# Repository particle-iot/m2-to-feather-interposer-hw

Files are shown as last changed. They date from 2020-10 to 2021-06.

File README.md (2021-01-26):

## M.2 to Feather socket Interposer adapter

### Summary:
Many of our customers have scaled on particle using the feather form factor in order to swap out between Cellular and WiFi products. Unfortunately we are seeing challenges with Cat M1 and the modem sizes that we can offer in the feather form factor. The SA team would like to propose an interposer board between a Particle M.2 Som to an interposer board that can be inserted into a feather socket on a customers PCB.

We recognize our customers may not be able to take advantage of the interposer board if their mechanical assembly does not accommodate the addition Z height and Width required by the addition of an interposer board and an M.2 Som

The interposer board will need to replicate some of the features not found on the M.2 Soms

#### Features:
* Nano SIM Tray
* PMIC, Same PMIC on Boron
* 3.3V@1A Buck regulator like Boron
* Top or Side pressed MODE and RESET buttons
* Enable pin support
* MCO/Board outline is slightly larger than a feather board due to SMT header.

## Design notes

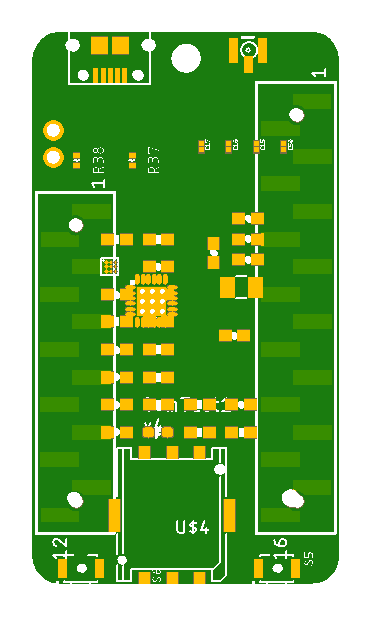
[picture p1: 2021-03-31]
m2_feather_interposer/m2_feather_interposer bottom side.png

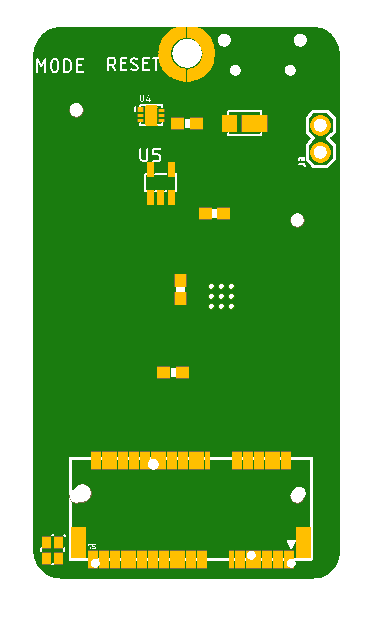
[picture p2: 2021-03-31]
m2_feather_interposer/m2_feather_interposer top side.png

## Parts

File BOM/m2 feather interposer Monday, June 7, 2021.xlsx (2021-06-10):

Done | DK PN | Qty | Value | Device | Package | Parts | Description | AVAILABILITY | DESCRIPTION | MF | MP | PACKAGE | POPULARITY | PRICE | PROD-ID | PROD_ID | PURCHASE-URL | SPICEPREFIX | VALUE
X |  | 1 |  | CONN_02 | 1X02 | J3 | Multi connection point. Often used as Generic Header-pin footprint for 0.1 inch spaced/style header connections
X | 311-0.0JRCT-ND | 2 | 0 | R-US_R0402 | R0402 | R11, R13 | RESISTOR, American symbol
X | 587-1220-1-ND | 1 | 0.001uF | C-USC0402 | C0402 | C11 | CAPACITOR, American symbol
X | 399-7760-1-ND | 1 | 0.01uF | C-USC0402 | C0402 | C1 | CAPACITOR, American symbol
X | 490-6042-1-ND | 1 | 0.047uF | C-USC0402 | C0402 | C12 | CAPACITOR, American symbol
X | 311-100KLRCT-ND | 1 | 100k | R-US_R0402 | R0402 | R17 | RESISTOR, American symbol
X | 490-14571-1-ND | 1 | 100nF | C-USC0201_B | C0201_B | C21 | Capacitor
x | 1276-6854-1-ND | 1 | 100nF | C-USC0603K | C0603K | C20 | CAPACITOR, American symbol |  |  |  |  |  | 5 |  |  |  |  | C
x | 490-14571-1-ND | 1 | 100nF | PARTICLE_C-USC0201_B | PARTICLE_C0201_B | C50 | Capacitor
x | 1276-3431-1-ND | 6 | 10K | R-US_R0402 | R0402 | R1, R9, R10, R11_, R15, R16 | RESISTOR, American symbol
X | 490-18214-1-ND | 6 | 10uF | RICKK2_CAP-10UF-0603 | RICKK2_0603-CAP | C4, C5, C6, C7, C9, C10 | CAP CER 10UF 16V X5R 0805 $ 0.21 |  |  |  |  |  |  |  |  |  |  |  | 10uF
X | 490-18214-1-ND | 2 | 10uF/10V | C-USC0603K | C0603K | C18, C19 | CAPACITOR, American symbol |  |  |  |  |  | 5 |  |  |  |  | C
X | P150LCT-ND | 1 | 150 | R-US_R0402 | R0402 | R5 | RESISTOR, American symbol
x | P20283CT-ND | 1 | 1K | R-US_R0402 | R-US_R0402 | R19 | 0402 Resistor
x | P20283CT-ND | 1 | 1K | R-US_R0402 | R0402 | R12 | RESISTOR, American symbol
x | P20283CT-ND | 3 | 1k | R-US_R0402 | R0402 | R2, R3, R4 | RESISTOR, American symbol
X | 490-10019-1-ND | 1 | 1uF | C-USC0402 | C0402 | C3 | CAPACITOR, American symbol
X | 587-2400-1-ND | 1 | 1uF | CAP-1UF-0603.DEV | 0603-CAP | C2 | CAP CER 1UF 25V X7R 0603 $ 0.10 |  |  |  |  |  |  |  |  |  |  |  | 1uF
X | SRP2512-2R2MCT-ND | 1 | 2.2uH | RICKK2_INDUCTOR-2.2UH | RICKK2_1008-BOURNS | L1 | 2.2uH inductor $0.31 **not ordered yet** |  |  |  |  |  |  |  |  |  |  |  | 2.2uH
X | 311-332LRCT-ND | 1 | 332 | R-US_R0402 | R0402 | R131 | RESISTOR, American symbol
X | 311-4.7KJRCT-ND | 3 | 4.7K | R-US_R0402 | R0402 | R6, R7, R8 | RESISTOR, American symbol
X | 1276-1903-1-ND | 1 | 4.7uF | RICKK2_CAP-4.7UF-0603 | RICKK2_0603-CAP | C8 | Murata X5R series |  |  |  |  |  |  |  |  |  |  |  | 4.7uF
X | 445-6668-1-ND | 1 | 4.7uH | INDUCTOR-SPARKFUNVLS3012ET-4R7M | INDUCTOR-VLS-E | L2 | Inductors
X | 490-14562-1-ND | 3 | 47pF | PARTICLE_C-USC0201_B | PARTICLE_C0201_B | C15, C16, C17 | Capacitor
X | P5.60KLCT-ND | 1 | 5.6K | R-US_R0402 | R0402 | R14 | RESISTOR, American symbol
X | SW1022CT-ND | 2 | B3U-3000P | B3U-3000P | SW_B3U-3000P | S1, S2 | Ultra-small Surface-mounting Tactile Switches with High Contact Reliability Check prices | Warning | Tactile Switch SPST-NO Side Actuated Surface Mount, Right Angle | Omron | B3U-3100P-B | Custom Package Omron |  | None |  |  | https://pricing.snapeda.com/search/part/B3U-3100P-B/?ref=eda
X | 296-49149-1-ND | 1 | BQ24195 | RICKK2_BQ24195 | RICKK2_24VFQN-TI | U2 | Texas Instruments BQ24195LRGER $2.93 |  |  |  |  |  |  |  |  |  |  |  | BQ24195
X | N/A | 2 | ESD NC | REDBEAR_RES0402S | REDBEAR_R-0402S | R37, R38 | RES
X | 2073-SIM8051-6-0-14-01-ACT-ND | 1 | M2_FEATHER_INTERPOSER_PARTICLE_SIM-NANO-4FF | M2_FEATHER_INTERPOSER_PARTICLE_SIM-NANO-4FF | M2_FEATHER_INTERPOSER_PARTICLE_GCT-SIM8100 | U$4 | SIM NANO 4FF
X | MAX17043G+U-ND | 1 | MAX1704X | MAX1704X | TDFN-8 | U3 | MAX17043/MAX17044: Battery Fuel Guage (43 is 1cell, 44 is 2cell) |  |  |  |  |  |  |  | IC-10399
X | TSM-112-01-T-SV-LC-ND |  | SAMTECH 12pin 2.54mm SMT
X | TSM-116-01-T-SV-LC-016-ND |  | SAMTECH 16pin 2.54mm SMT
 | PN in row 32/33 | 1 | MICROBUILDER_FEATHERWINGSMT_BTM_FEATHER | MICROBUILDER_FEATHERWINGSMT_BTM_FEATHER | SMT_BTM_FEATHERWING | MS1
X | 160-1447-1-ND | 1 | RED | LED-RED0603 | LED-0603 | D3 | Red SMD LED |  |  |  |  |  |  |  |  | DIO-00819 |  |  | RED
X | 160-1830-1-ND | 1 | RED | RICKK2_LED-RED | RICKK2_LED-0603 | D1 | LED RED CLEAR 0603 SMD $0.41 |  |  |  |  |  |  |  |  |  |  |  | RED
X | CLMVC-FKA-CL1D1L71BB7C3C3CT-ND | 1 | RICKK2_LED-RGB-CREE-SMD | RICKK2_LED-RGB-CREE-SMD | RICKK2_LED-RGB-CREE-SMD | LED1 | LED RGB DIFFUSED 4SMD $ 0.35
X | 732-7078-1-ND | 1 | RICKK2_M2-STANDOFF | RICKK2_M2-STANDOFF | RICKK2_M2-STANDOFF | U$1 | https://www.digikey.com/product-detail/en/jae-electronics/SM3ZS067U310-NUT1-R1800/670-2864-1-ND/5955848
X | A115904CT-ND | 1 | RICKK2_SPARK_M.2EKEY | RICKK2_SPARK_M.2EKEY | RICKK2_SPARK_M.2EKEY-LESS-CREAM | J1 | $1.42
X | 67T2260 | 1 | RICKK2_USB-MICRO-B-SOCKET-AMPHENOL | RICKK2_USB-MICRO-B-SOCKET-AMPHENOL | RICKK2_USB-B-SMT-AMPHENOL | U$3 | CONN USB MICRO B RECPT SMT R/A $0.42
X | RS1JFPCT-ND | 1 | RS1JFP | RICKK2_DIODE-RS1JFP | RICKK2_SOD-123HE-ON | D2 | Reverse voltage protection diode - not ordered yet! |  |  |  |  |  |  |  |  |  |  |  | RS1JFP
X | 931-1107-1-ND | 1 | UFL | PARTICLE_IPEX-20279-001E | PARTICLE_IPEX-20279-001E | NFC | Ultra Miniature Coaxial SMT RF Receptacle
X | 865-XC8107BC20MR-G | 1 | XC8107SOT25 | XC8107SOT25 | SOT25 | U7
X | 865-XC9258A33EER-G | 1 | XC9258A33EER-G | XC9258A33EER-G | USP-6C | U6 | 1.0A Synchronous Step-Down DC/DC Converters

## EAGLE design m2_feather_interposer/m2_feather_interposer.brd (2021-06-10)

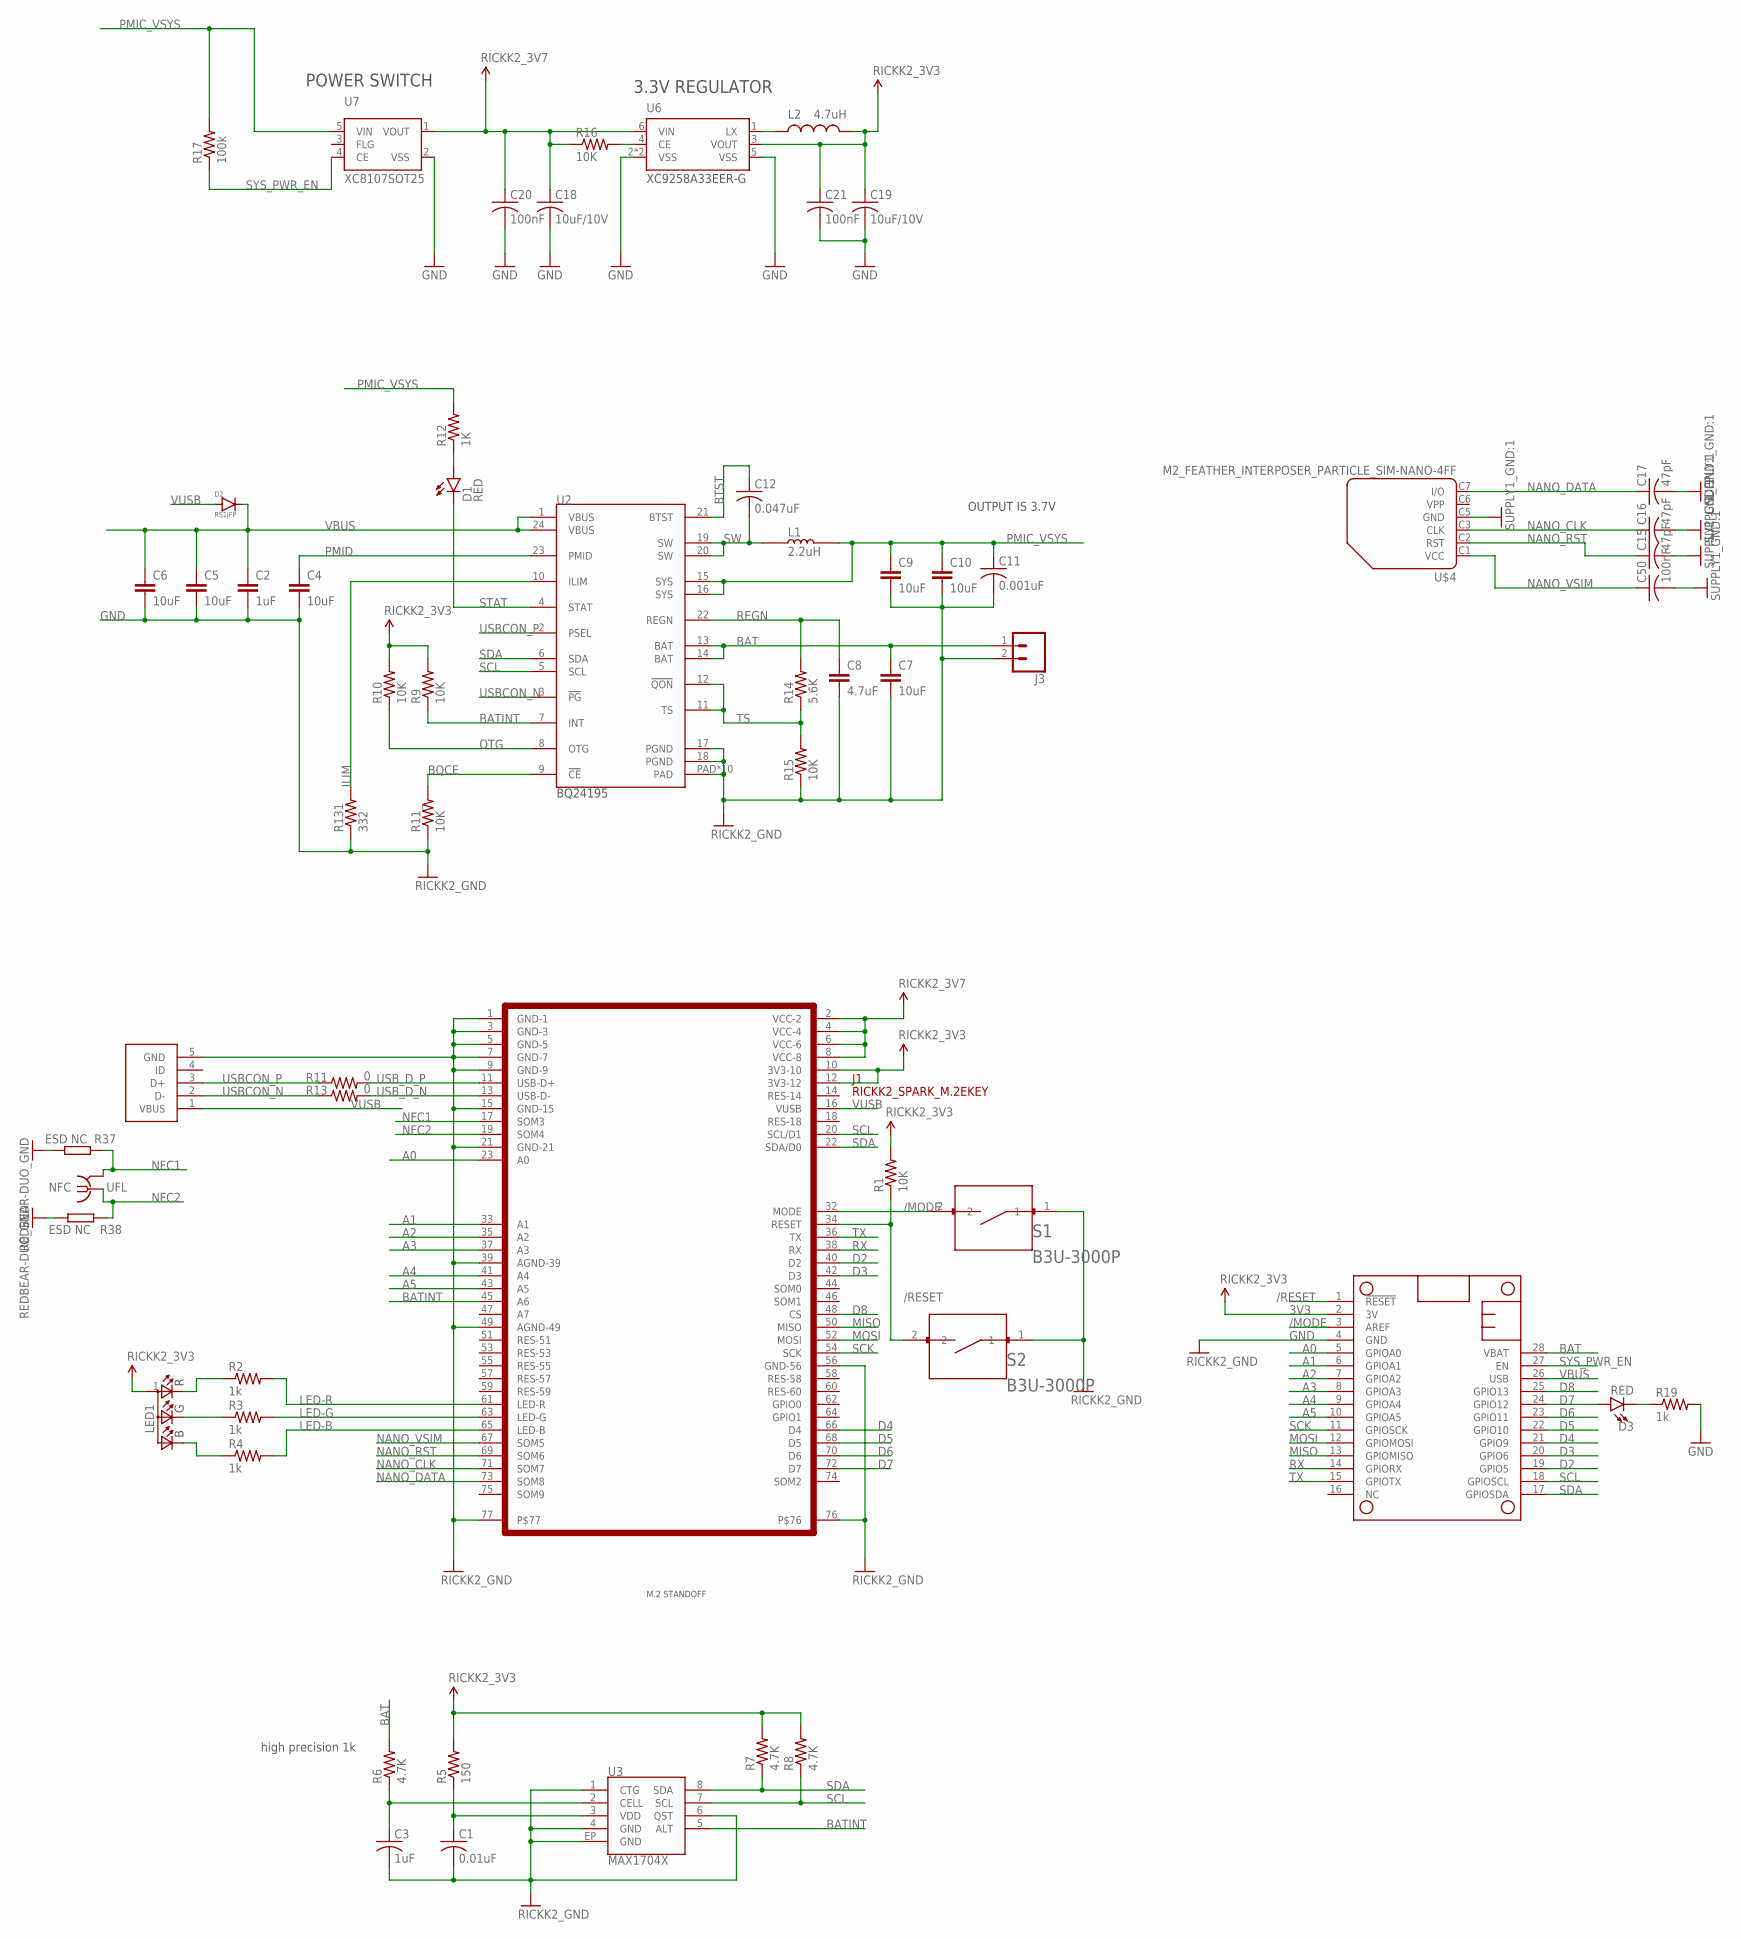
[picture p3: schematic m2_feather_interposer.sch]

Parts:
C1: 0.01uF; C0402
C2: 1uF; 0603-CAP
C3: 1uF; C0402
C4, C5, C6, C7, C9, C10: 10uF; RICKK2_0603-CAP
C8: 4.7uF; RICKK2_0603-CAP
C11: 0.001uF; C0402
C12: 0.047uF; C0402
C15, C16, C17: 47pF; PARTICLE_C0201_B
C18, C19: 10uF/10V; C0603K
C20: 100nF; C0603K
C21: 100nF; C0201_B
C50: 100nF; PARTICLE_C0201_B
D1: RED; RICKK2_LED-0603
D2: RS1JFP; RICKK2_SOD-123HE-ON
D3: RED; LED-0603
J1: RICKK2_SPARK_M.2EKEY; RICKK2_SPARK_M.2EKEY-LESS-CREAM
J3: CONN_02; 1X02
L1: 2.2uH; RICKK2_1008-BOURNS
L2: 4.7uH; INDUCTOR-VLS-E
LED1: RICKK2_LED-RGB-CREE-SMD
MS1: MICROBUILDER_FEATHERWINGSMT_BTM_FEATHER; SMT_BTM_FEATHERWING
NFC: UFL; PARTICLE_IPEX-20279-001E
R1, R9, R10, R11_, R15, R16: 10K; R0402
R2, R3, R4, R19: 1k; R0402
R5: 150; R0402
R6, R7, R8: 4.7K; R0402
R11, R13: 0; R0402
R12: 1K; R0402
R14: 5.6K; R0402
R17: 100k; R0402
R37, R38: ESD NC; REDBEAR_R-0402S
R131: 332; R0402
S1, S2: B3U-3000P; SW_B3U-3000P
U2: BQ24195; RICKK2_24VFQN-TI
U3: MAX1704X; TDFN-8
U6: XC9258A33EER-G; USP-6C
U7: XC8107SOT25; SOT25
U$1: RICKK2_M2-STANDOFF
U$3: RICKK2_USB-MICRO-B-SOCKET-AMPHENOL; RICKK2_USB-B-SMT-AMPHENOL
U$4: M2_FEATHER_INTERPOSER_PARTICLE_SIM-NANO-4FF; M2_FEATHER_INTERPOSER_PARTICLE_GCT-SIM8100

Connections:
3V3: C19.1, C21.1, J1.10 (3V3-10), J1.12 (3V3-12), L2.P$2 (2), LED1.1 (A), MS1.2 (3V), R1.2, R5.2, R7.2, R8.2, R9.2, R10.2, U6.3 (VOUT)
3V7: C18.1, C20.1, J1.2 (VCC-2), J1.4 (VCC-4), J1.6 (VCC-6), J1.8 (VCC-8), R16.1, U6.6 (VIN), U7.1 (VOUT)
/MODE: J1.32 (MODE), MS1.3 (AREF), S1.2
/RESET: J1.34 (RESET), MS1.1 (!RESET), R1.1, S2.2
A0: J1.23 (A0), MS1.5 (GPIOA0)
A1: J1.33 (A1), MS1.6 (GPIOA1)
A2: J1.35 (A2), MS1.7 (GPIOA2)
A3: J1.37 (A3), MS1.8 (GPIOA3)
A4: J1.41 (A4), MS1.9 (GPIOA4)
A5: J1.43 (A5), MS1.10 (GPIOA5)
BAT: C7.1, J3.1, MS1.28 (VBAT), R6.2, U2.13 (BAT), U2.14 (BAT)
BATINT: J1.45 (A6), R9.1, U2.7 (INT), U3.5 (ALT)
BQCE: R11_.2, U2.9 (!CE)
BTST: C12.1, U2.21 (BTST)
D2: J1.40 (D2), MS1.19 (GPIO5)
D3: J1.42 (D3), MS1.20 (GPIO6)
D4: J1.66 (D4), MS1.21 (GPIO9)
D5: J1.68 (D5), MS1.22 (GPIO10)
D6: J1.70 (D6), MS1.23 (GPIO11)
D7: D3.A, J1.72 (D7), MS1.24 (GPIO12)
D8: J1.48 (CS), MS1.25 (GPIO13)
GND: C1.2, C2.2, C3.2, C4.2, C5.2, C6.2, C7.2, C8.2, C9.2, C10.2, C11.2, C15.2, C16.2, C17.2, C18.2, C19.2, C20.2, C21.2, C50.2, J1.1 (GND-1), J1.3 (GND-3), J1.5 (GND-5), J1.7 (GND-7), J1.9 (GND-9), J1.15 (GND-15), J1.21 (GND-21), J1.39 (AGND-39), J1.49 (AGND-49), J1.56 (GND-56), J1.76, J1.77, J3.2, MS1.4 (GND), R11_.1, R15.1, R19.2, R37.2, R38.1, R131.1, S1.1, S2.1, U2.17 (PGND), U2.18 (PGND), U2.PAD, U2.PAD@1 (PAD), U2.PAD@2 (PAD), U2.PAD@3 (PAD), U2.PAD@4 (PAD), U2.PAD@5 (PAD), U2.PAD@6 (PAD), U2.PAD@7 (PAD), U2.PAD@8 (PAD), U2.PAD@9 (PAD), U3.1 (CTG), U3.4 (GND), U3.6 (QST), U3.EP (GND), U6.2 (VSS), U6.5 (VSS), U6.P$1 (VSS), U7.2 (VSS), U$3.5 (GND), U$4.C5 (GND)
ILIM: R131.2, U2.10 (ILIM)
LED-B: J1.65 (LED-B), R4.2
LED-G: J1.63 (LED-G), R3.2
LED-R: J1.61 (LED-R), R2.2
MISO: J1.50 (MISO), MS1.13 (GPIOMISO)
MOSI: J1.52 (MOSI), MS1.12 (GPIOMOSI)
unnamed: LED1.3 (G), R3.1
unnamed: C3.1, R6.1, U3.2 (CELL)
unnamed: C1.1, R5.1, U3.3 (VDD)
unnamed: LED1.4 (R), R2.1
unnamed: D1.A, R12.1
unnamed: LED1.2 (B), R4.1
unnamed: R16.2, U6.4 (CE)
unnamed: D3.C, R19.1
unnamed: L2.P$1 (1), U6.1 (LX)
NANO_CLK: C16.1, J1.71 (SOM7), U$4.C3 (CLK)
NANO_DATA: C17.1, J1.73 (SOM8), U$4.C7 (I/O)
NANO_RST: C15.1, J1.69 (SOM6), U$4.C2 (RST)
NANO_VSIM: C50.1, J1.67 (SOM5), U$4.C1 (VCC)
NFC1: J1.17 (SOM3), NFC.2@1 (GND), NFC.2@2 (GND), R37.1
NFC2: J1.19 (SOM4), NFC.1, R38.2
OTG: R10.1, U2.8 (OTG)
PMIC_VSYS: C9.1, C10.1, C11.1, L1.2, R12.2, R17.2, U2.15 (SYS), U2.16 (SYS), U7.5 (VIN)
PMID: C4.1, U2.23 (PMID)
REGN: C8.1, R14.2, U2.22 (REGN)
RX: J1.38 (RX), MS1.14 (GPIORX)
SCK: J1.54 (SCK), MS1.11 (GPIOSCK)
SCL: J1.20 (SCL/D1), MS1.18 (GPIOSCL), R8.1, U2.5 (SCL), U3.7 (SCL)
SDA: J1.22 (SDA/D0), MS1.17 (GPIOSDA), R7.1, U2.6 (SDA), U3.8 (SDA)
STAT: D1.C, U2.4 (STAT)
SW: C12.2, L1.1, U2.19 (SW), U2.20 (SW)
SYS_PWR_EN: MS1.27 (EN), R17.1, U7.4 (CE)
TS: R14.1, R15.2, U2.11 (TS), U2.12 (!QON)
TX: J1.36 (TX), MS1.15 (GPIOTX)
USBCON_N: R13.1, U2.3 (!PG), U$3.2 (D-)
USBCON_P: R11.1, U2.2 (PSEL), U$3.3 (D+)
USB_D_N: J1.13 (USB-D-), R13.2
USB_D_P: J1.11 (USB-D+), R11.2
VBUS: C2.1, C5.1, C6.1, D2.1 (CATHODE), MS1.26 (USB), U2.1 (VBUS), U2.24 (VBUS)
VUSB: D2.2 (ANODE), J1.16 (VUSB), U$3.1 (VBUS)

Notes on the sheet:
3.3V REGULATOR
POWER SWITCH
OUTPUT IS 3.7V
high precision 1k

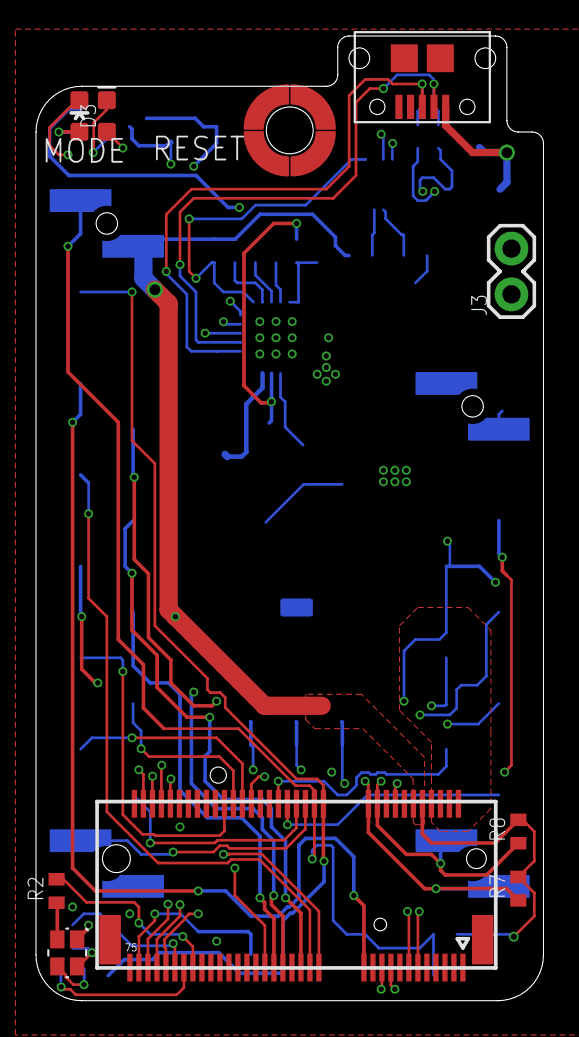
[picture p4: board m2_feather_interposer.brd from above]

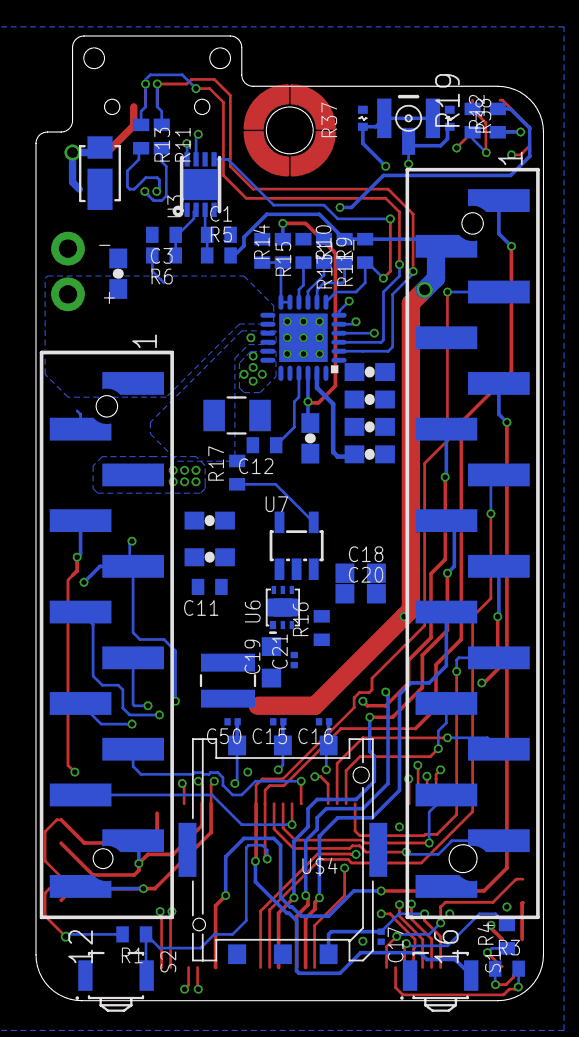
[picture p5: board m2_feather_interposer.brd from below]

Board: 4 copper layers, 28.2 x 53.6 mm, 61 parts (50 on the bottom side), 62 nets.

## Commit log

2020-10-30 added base files for the project
    [m2_feather_interposer.brd, m2_feather_interposer.sch]
2020-10-30 added ricks basic som design as a base
    [SomTest1.brd, SomTest1.sch]
2021-01-26 added a whole bunch of stuff, board layout, draft key component placements, added connectors, added components from the boron that were missing.
    [m2_feather_interposer.brd, m2_feather_interposer.sch]
2021-03-31 all components added and key component placement done, driving through layout draft
    [m2_feather_interposer.brd, m2_feather_interposer.sch]
2021-04-01 GPIO:draft layout done, LED: draft layout done, Buttons:draft layout done, SIM: draft layout done, NFC: draft layout done. Open items: fuel gauge, pmic, 3.3V reg
    [m2_feather_interposer.brd, m2_feather_interposer.sch]
2021-04-01 working through pmic, 3.3V and pwr switch layout:
    [m2_feather_interposer.brd, m2_feather_interposer.sch]
2021-06-10 added draft bom
    [m2 feather interposer Monday, June 7, 2021.xlsx, m2_feather_interposer BOM Monday, June 7, 2021.csv, m2_feather_interposer.brd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]

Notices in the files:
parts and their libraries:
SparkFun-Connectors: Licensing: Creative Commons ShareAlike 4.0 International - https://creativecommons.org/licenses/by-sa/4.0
